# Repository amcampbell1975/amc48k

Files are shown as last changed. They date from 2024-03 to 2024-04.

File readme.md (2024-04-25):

# AMC48K
48 key Ortholinear keyboard.

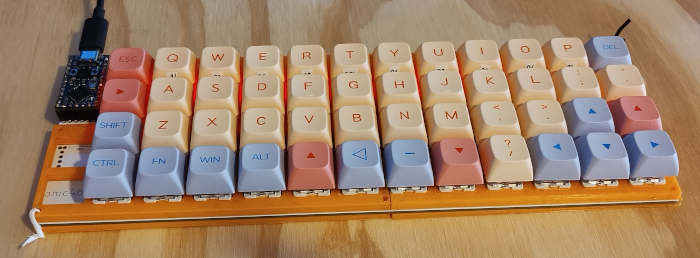
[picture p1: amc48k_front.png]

- RP2040 promicro.
- 48 RGB leds
- Rotary encoder
- 3D printed case, and plate.

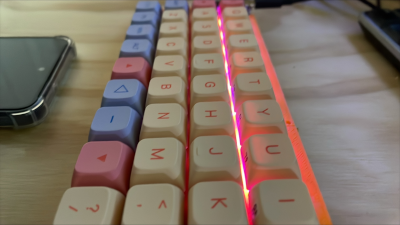
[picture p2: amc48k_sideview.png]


# How to Build
- [Components](components/bom.md) required.
- [PCB](pcb/readme.md) created using kicad
- [Case](case/readme.md) 3d printed. Created using openscad.

# QMK Features
- Caps word  (tap both shift to activate next word caps lock)
- Mouse emulation
  - FN "Arrow keys" 
- Dynamic Macros: Record and Replay Macros in Runtime
  - Lower "a" record 1
  - Lower "z" play 1
  - Lower "s" record 2
  - Lower "x" play 2
  - Lower "d" Stop recording 

# Other stuff...

## RP2040 startup
[Double tap bootmode](https://docs.qmk.fm/#/platformdev_rp2040?id=double-tap)  This is enabled be default.

## ANSI vs ISO backslash
I use a UK (ISO) keyboard layout in the OS, however the keycaps are US (ANSI) style
- KC_NONUS_BACKSLASH	KC_NUBS	Non-US \ and |	✔	✔	✔
- KC_BACKSLASH	KC_BSLS	\ and |	✔	✔	✔
- KC_NONUS_HASH	KC_NUHS	Non-US # and ~	✔	✔	✔

## to do 
- Rotary encoder

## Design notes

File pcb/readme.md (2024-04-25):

# PCB 
kicad

[kicad zip](amc48k_MANAFACTURED.zip)

# Schematic 
[amc48k.pdf](amc48k.pdf)

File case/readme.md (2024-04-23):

# Plate


## Split for small 3d printer bed.


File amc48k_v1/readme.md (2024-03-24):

# amc48k/amc48k_v1

amc48k/amc48k_v1

*A short description of the keyboard/project*

* Keyboard Maintainer: [amc](https://github.com/amc)
* Hardware Supported: *The PCBs, controllers supported*
* Hardware Availability: *Links to where you can find this hardware*

Make example for this keyboard (after setting up your build environment):

    make amc48k/amc48k_v1:default

Flashing example for this keyboard:

    make amc48k/amc48k_v1:default:flash

See the [build environment setup](https://docs.qmk.fm/#/getting_started_build_tools) and the [make instructions](https://docs.qmk.fm/#/getting_started_make_guide) for more information. Brand new to QMK? Start with our [Complete Newbs Guide](https://docs.qmk.fm/#/newbs).

## Bootloader

Enter the bootloader in 3 ways:

* **Bootmagic reset**: Hold down the key at (0,0) in the matrix (usually the top left key or Escape) and plug in the keyboard
* **Physical reset button**: Briefly press the button on the back of the PCB - some may have pads you must short instead
* **Keycode in layout**: Press the key mapped to `QK_BOOT` if it is available

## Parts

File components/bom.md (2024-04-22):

# Bill of Materials 
What is requried.

## keycaps
PBT Keycap XDA Highly Sublimated Technology Personalized Key Caps For Cherry MX Switch Game Mechanical Keyboard. Cotton candy theme

https://www.aliexpress.com/item/1005005732144367.html

￡6.84 + Tax + Shipping



## Switches (48 required)
10Pcs 3 Pin KeyCaps Brofwn Mechanical Keyboard Switch for Cherry MX Keyboard

https://www.aliexpress.com/item/33007890748.html

£1.33 * 5 = £6.65 + Tax + Shipping



## Hot Swap Switches (48 required)
Kailh Hot-swappable PCB socket Hot Plug (qty 50)

https://www.aliexpress.com/item/1005006105695230.html

£5.51 + Tax + Shipping

![image](https://git
£0.91 + Taxhub.com/amcampbell1975/amc48k/assets/65419433/901e2cca-c47a-4f12-8009-df3bff7874ff)

## Diodes (48 Required)
1N4148 SOD-123 

https://www.aliexpress.com/item/1005006207944104.html

£0.91 + Tax + Shipping



## Micro Controller Socket.
10 x Pair Plug Jack (Male & Female required)

https://www.aliexpress.com/item/1005002545449541.html

£1.45 + Tax + Shipping



## RGB LEDS (48 required)
SK6812 MINI-E  (Make sure it is the "MINI-E" as the MINI has a different package)

https://www.aliexpress.com/item/1005005473596808.html

£4.01 + Tax + Shipping



## Cap for LEDs (48 requried)
10uf caps 0805 SMD Chip Multilayer Ceramic Capacitor
https://www.aliexpress.com/item/1005005690917856.html

£0.69 + Tax + Shipping



## Micro Controller RP2040 with promicro footprint.
RP2040 with promicro footprint. 
RP2040 Pro Micro Raspberry PI PICO Development Board Dual-Core

https://www.aliexpress.com/item/1005006377576656.html

£3.68  + Tax + Shipping



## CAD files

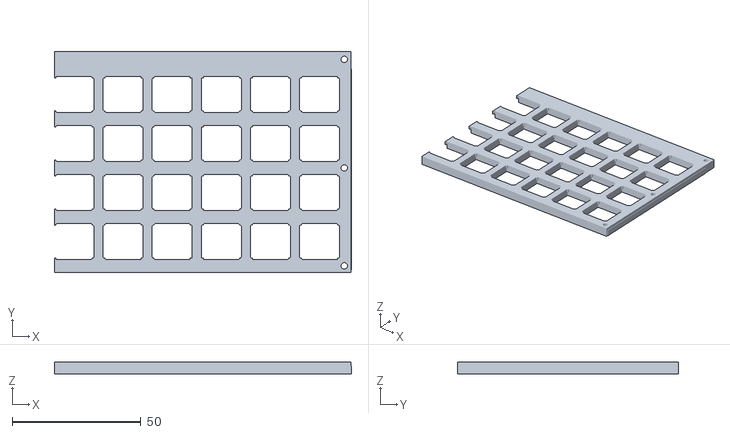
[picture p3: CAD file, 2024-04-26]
case/plate_right_v4.stl
115.2 x 85.8 x 4.50

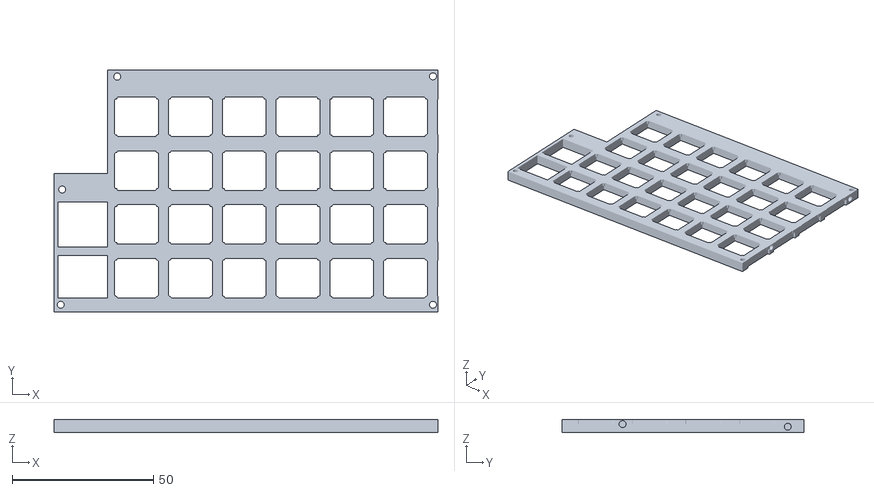
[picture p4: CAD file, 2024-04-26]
case/plate_left_v4.stl
136.0 x 85.8 x 4.50

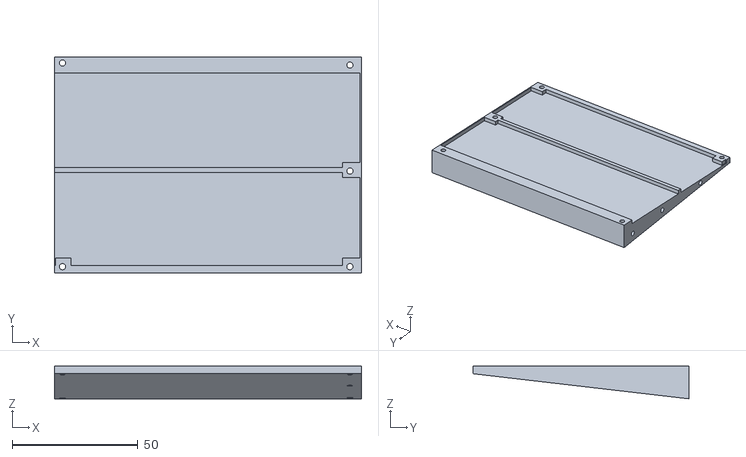
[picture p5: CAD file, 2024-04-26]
case/case_bottom_right_v2.stl
122.0 x 86.0 x 13.0

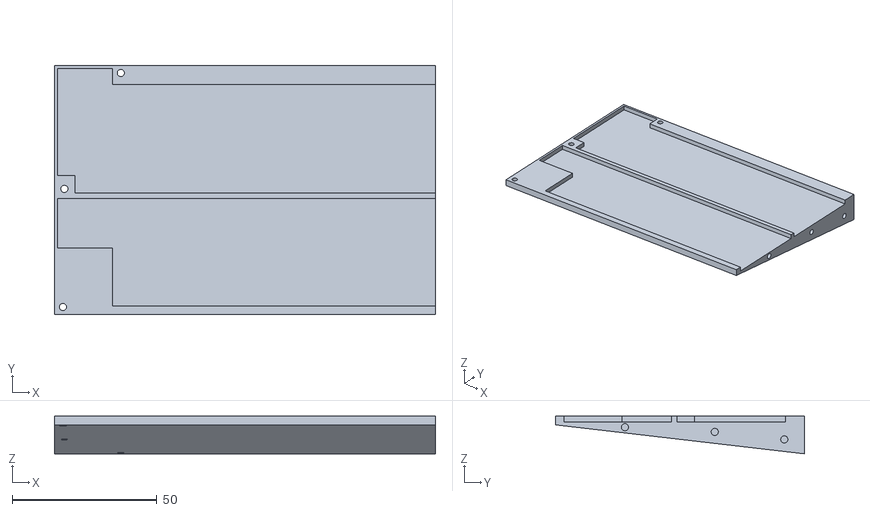
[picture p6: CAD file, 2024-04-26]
case/case_bottom_left_v2.stl
131.5 x 86.0 x 13.0

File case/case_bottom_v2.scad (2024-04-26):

$fn=20;

$CASE_THICKNESS = 3; // minus 3d printer tolerence



if (false)
    translate([0,0,-4])
    color("gray",1)
    rotate([180,180,180])
    translate([-45.9,129 ,-4.7])
    import ("amc48k_PCBv2.stl");


translate([0,0,-8.2]) 
difference()
{
 intersection()
 {  
     
     //$CHOP_POINT=119+(19.02*0)+0.4;  // Half and half chop point
     $CHOP_POINT=24+(19.02*6)+0.4-5;  // Half and half chop point
     //$CHOP_POINT=24+(19.02*1)+0.4;  // Half and half chop point
     
     // Small print section
//     rotate([0,0,3]) // rotate to create a diagonal split of the 2 halfs.
     {  
         if (false){
            translate([-100,-100,-10])
    //        cube([119,192,20]); //1x4
    //        cube([140,142,20]); //3x3
              cube([900,900,20]);  // Everything
         }
        else{
            //////////////////////////////
            // Half and half
            //////////////////////////////
            
            if(false){//6x4_left
                translate([-24,-30,-30])
                cube([$CHOP_POINT,192,40]); 
            }else{ //6x4_right
                translate([-24,-30,-30])
                translate([$CHOP_POINT,0,0])
                cube([$CHOP_POINT,192,40]); 
            }
         
        }
    }
    union(){
        
        //Main body
        translate([-22,-5,0])
        color("orange")    
        //cube([232,86-0.3,$PLATE_THICKNESS]);
        cube([235+18.5,86,$CASE_THICKNESS]);
    
   
        //Sloping base
        color("green")
        translate([-22,-5,0]) 
        rotate([0,90,0])
        linear_extrude(height = 235+18.5, center = false, convexity = 10, twist = 0, slices = 20, $fn = 16)
        polygon(points=[[0,0],[10,86],[0,86]]);
    }
         
    //         else
    //             translate([-5+2.5-18.5,-5,0])
    //             color("re2")    
    //             cube([235+18.5,86,$PLATE_THICKNESS]);
    //         
    //         
    //         
    //         linear_extrude(height=5, center=true, convexity= 10){
    //             import("kbplate.svg");
    //         }
    //     }
    // }    
 }
 // Remove bolt holes
 // Bolt Hole bottom left
 translate([-19.1,-2.4,-10])
 cylinder(h=20,d=2.5);

 // Bolt Hole Middle left
 translate([-19.1,-2.4,-10])
 translate([0.5,40.8,0])
 cylinder(h=20,d=2.5);

 // Bolt Hole Top left
 translate([-19.1,-2.4,-10])
 translate([20,80.8,0])
 cylinder(h=20,d=2.5);

 // Bolt Hole Top middle
 translate([-19.1,-2.4,-10])
 translate([131.8,80.9,0])
 cylinder(h=20,d=2.5);
 
 // Bolt Hole Bottom middle
 translate([-19.1,-2.4,-10])
 translate([131.8,0.0,0])
 cylinder(h=20,d=2.5);

 // Bolt Hole Bottom right
 translate([-19.1,-2.4,-10])
 translate([246.0,0.0,0])
 cylinder(h=20,d=2.5);
 
 // Bolt Hole middle right
 translate([-19.1,-2.4,-10])
 translate([246.0,38.0,0])
 cylinder(h=20,d=2.5);

 // Bolt Hole Top right
 translate([-19.1,-2.4,-10])
 translate([246.0,80.1,0])
 #cylinder(h=20,d=2.5);
 
 // Horizonal join top
 translate([107.0-40,76.0-2,-5])
 rotate([0,90,0])
 #cylinder(h=80,d=2.5);

 // Horizonal join middle
 translate([107.0-40,50.0,-2.4])
 rotate([0,90,0])
 #cylinder(h=80,d=2.5);
 
  // Horizonal join bottom
 translate([109.9-40,19,-0.8])
 rotate([0,90,0])
 #cylinder(h=80,d=2.5);
 
 difference(){
    translate([-21.0,-4,1])
    cube([252.5-0.5,84,$CASE_THICKNESS-0.5]);
    
    // Bottom left 
    translate([-21.0,-4,1])
    cube([19,22,$CASE_THICKNESS-0.5]);
    
    // Left middle 
    translate([-21.0,35,1])
    cube([6,8,$CASE_THICKNESS-0.5]);

    // Left middle 
    translate([224.0,33,1])
    cube([7,6,$CASE_THICKNESS-0.5]);
        
    // Top edge
    translate([-2,74.5,1])
    cube([233,5.5,$CASE_THICKNESS-0.5]);
      
    // Bottom edge
    translate([-2,-5,1])
    cube([233,3,$CASE_THICKNESS-0.5]);

    // Middle support
    translate([-21,35,1])
    cube([245,2,$CASE_THICKNESS-0.5]);
    
    // middle bottom
    translate([110.0,-5,1])
    cube([6,6,$CASE_THICKNESS-0.5]);
        
    // middle right
    translate([224.0,-5,1])
    cube([7,6,$CASE_THICKNESS-0.5]);
  
 }

}



 
 
//#linear_extrude(height=5, center=true, convexity= 10){
//         import("kbplate_bot.svg");
//}
 
 
 if(false)
 translate([8,7,12])
{

	//1. steam
	color("brown"){
		//1.1. l-r tab is 1.35mm
		translate([0,0,-3.62/2])
			cube([1.35,4.5,3.62], center=true);
		//1.2. f-b tab is 1.15mm. it has a smal notch that i will ignore.
		translate([0,0,-3.62/2])
			cube([4.5,1.15,3.62], center=true);
		//1.3. base. it has a chamfered top that i will ignore.
		translate([0,0,-5.62])
			cube([7.2,5.56,4], center=true);
	}
	// 2. top
	color("grey"){
		difference(){
			// make a trapezoid with the general shape (volume?) of the top
			hull(){
				translate([0,0,-4]) //distance from top of switch... some i measured 3.9 others 4.2... so leaving at 4
					cube([9.87,10.62,0.1], center=true);
				translate([0,0,-4 -5.2]) // bottom has a measured 5.3... so move 5.2 and use the 0.1 bellow
					cube([14.58,14.58,0.1], center=true);
			}

		// and subtract:
		// the front led. NOTE: totally off... measured by eye. just for astetics
		// adding just so there is a visual cue of the direction
			translate([0,-4.7,-6])
				cylinder(r=3/2, h=6, center=true);
			translate([0,-5.5,-6])
				cube([8,4,5], center=true);
		// the four corners
			// TODO waste of time? this is all for looks, you shouldn't invade any of that space anyway...
		}
	}

	// 3. bottom
	color("green")
		// 3.1 main body volume
		hull(){
				translate([0,0,-4 -5.3]) //steam + top
					cube([13.98,13.98,0.1], center=true);
				translate([0,0,-4 -5.3 -2.2]) //steam + top + straigth part
					cube([13.98,13.98,0.1], center=true);
				translate([0,0,-4 -5.3 -5.5]) //steam + top + bottom (measured 5.5)
					cube([12.74,13.6,0.1], center=true);
		}
		// 3.2 tabs
		// note: only measured the lenght, if they are slightly off-center, this will be all wrong :)
		color("black")
		difference(){
			translate([0,0,-4 -5.3 -0.82/2]) //steam + top
				cube([15.64,15.64,0.82], center=true);
			translate([0,0,-4 -5.3 -0.82/2  ]) // front-back cut
				cube([5.64,20,0.82 +2], center=true);
			translate([0,0,-4 -5.3 -0.82/2  ]) //side cut
				cube([20,11.64,0.82 +2], center=true);
		}

		// 3.3 tab (plate snap on). to use this mechanically, you have to take into account the bending (as it will move the bottom part slightly up...) just for gross reference here for now
		color("white"){
			// 3.3.1 top
			translate([0,0,-4 -5.3 -0.82/2  ]) // front-back cut
				cube([1.82,16.33,0.82], center=true);
			// 3.3.2 bottom
			difference(){
				hull(){
					translate([0,0,-4 -5.3 -0.82/2 -1.76  ]) // front-back cut
						cube([3.65,14,0.1], center=true);
					translate([0,0,-4 -5.3 -0.82/2 -2.2  ]) // front-back cut
						cube([3.65,14.74,0.1], center=true);
					translate([0,0,-4 -5.3 -0.82/2 -2.89  ]) // front-back cut
						cube([3.65,14,0.1], center=true);
				}
				translate([0,0,-4 -5.3 -0.82/2 -1.76   ]) // front-back cut
					cube([2.2,20,4], center=true);

			}
		}

		// 4. bottom guides
		// again, i'm assuming everything is centered...
		color("darkGreen"){
			// 4.1 cylinder
			translate([0,0,-4 -5.3 -5.5 -2/2]) //steam + top + bottom (measured 5.5)
				cylinder(r=3.85/2, h=2, center=true);
			translate([0,0,-4 -5.3 -5.5 -2 -1/2]) //steam + top + bottom (measured 5.5)
				cylinder(r2=3.85/2, r=2.8/2, h=1, center=true);
			// 4.2 PCB pins
			translate([4.95,0,-4 -5.3 -5.5 -2/2]) //steam + top + bottom (measured 5.5)
				cylinder(r=1.6/2, h=2, center=true);
			translate([4.95,0,-4 -5.3 -5.5 -2 -1/2]) //steam + top + bottom (measured 5.5)
				cylinder(r2=1.6/2, r=1/2, h=1, center=true);
			translate([-4.95,0,-4 -5.3 -5.5 -2/2]) //steam + top + bottom (measured 5.5)
				cylinder(r=1.6/2, h=2, center=true);
			translate([-4.95,0,-4 -5.3 -5.5 -2 -1/2]) //steam + top + bottom (measured 5.5)
				cylinder(r2=1.6/2, r=1/2, h=1, center=true);
		}

		// 5. pins
		color("orange"){
			translate([-3.77,2.7,-4 -5.3 -5.5 -3.1/2]) //steam + top + bottom (measured 5.5)
				cube([.86, 0.2,3.1], center=true);
			translate([2.7,5.2,-4 -5.3 -5.5 -3.1/2]) //steam + top + bottom (measured 5.5)
				cube([.86, 0.2,3.1], center=true);
		}

}

 
 /*
 }
 */
 

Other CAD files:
case/plate_v4.scad

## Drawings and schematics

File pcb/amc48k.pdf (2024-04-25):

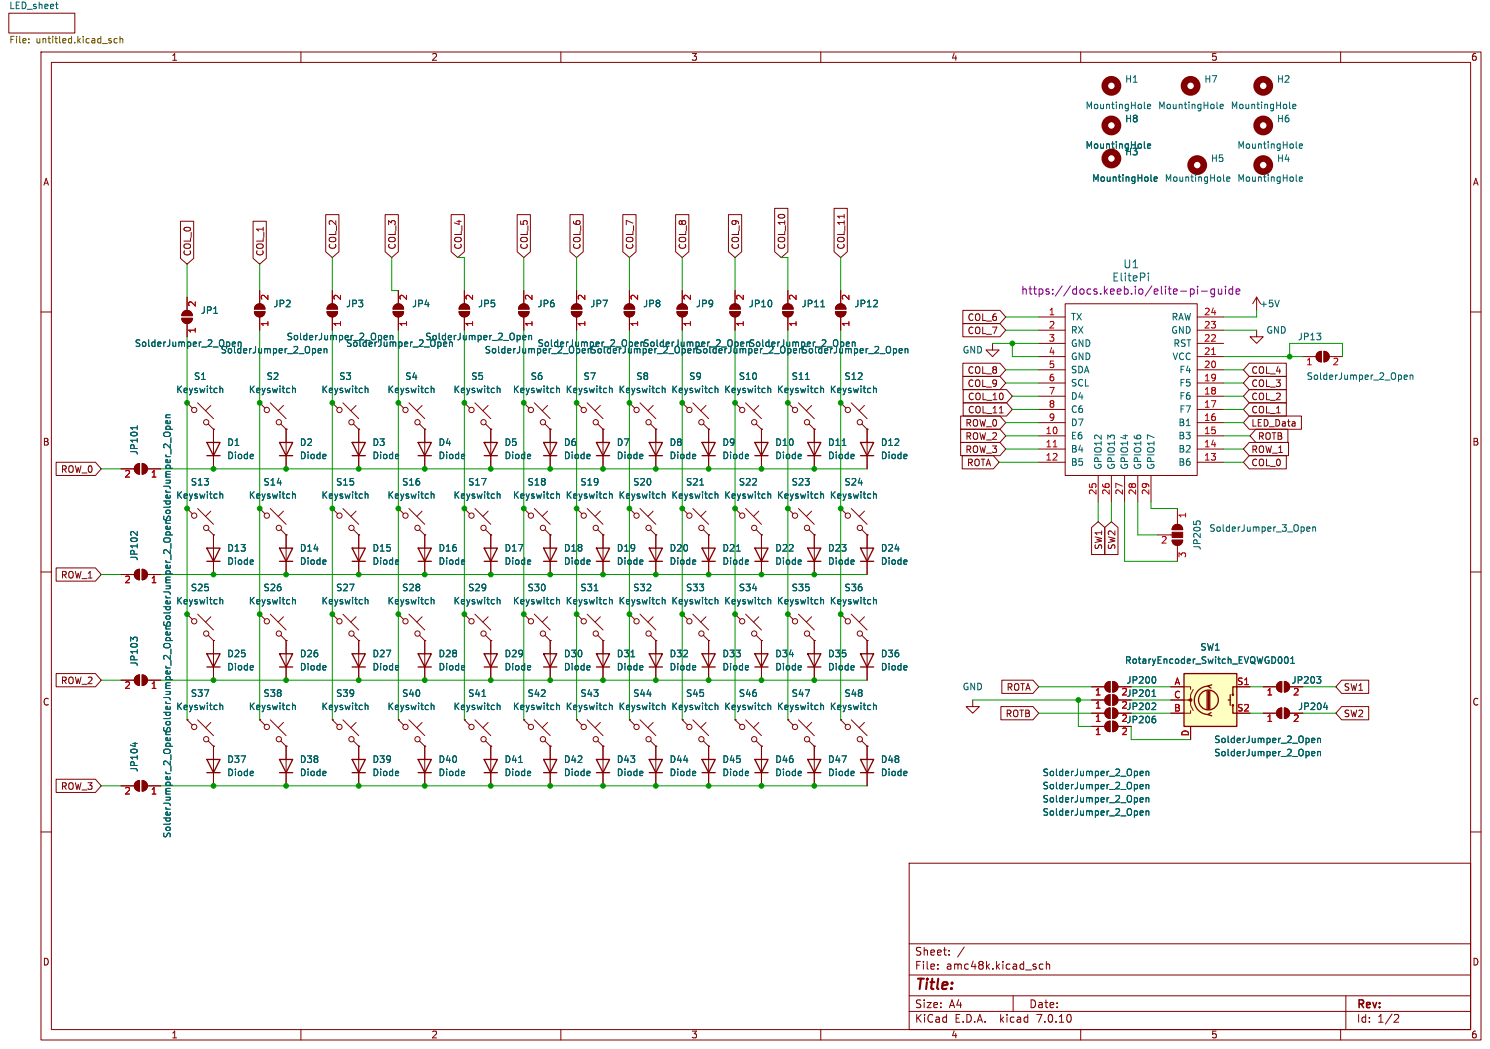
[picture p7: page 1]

1 2 H8 MountingHole H3 MountingHole D46 Diode D45 Diode S47 Keyswitch S46 Keyswitch D34 Diode D33 Diode D48 Diode S48 Keyswitch D47 Diode D35 Diode D36 Diode S45 Keyswitch D23 Diode D24 Diode S35 Keyswitch D22 Diode S36 Keyswitch S34 Keyswitch S33 Keyswitch D21 Diode SW1 RotaryEncoder_Switch_EVQWGD001 A

1 2 JP6 SolderJumper_2_Open D44 Diode D3 Diode S14 Keyswitch S41 Keyswitch D17 Diode S17 Keyswitch S28 Keyswitch S16 Keyswitch D16 Diode S29 Keyswitch S40 Keyswitch D40 Diode D2 Diode S30 Keyswitch S18 Keyswitch S19 Keyswitch D41 DiodeS42 Keyswitch S20 Keyswitch D29 Diode D28 Diode D20 Diode S3 Keyswitch D1 Diode S2 Keyswitch S1 Keyswitch D18 Diode D30 Diode D19 Diode COL_2

1 2 D3 Diode S14 Keyswitch S3 Keyswitch S2 Keyswitch S1 Keyswitch D1 Diode D2 Diode S15 Keyswitch JP101 SolderJumper_2_Open 2 1 S13 Keyswitch
JP1 SolderJumper_2_Open

1 2 JP9 SolderJumper_2_Open D36 Diode S45 Keyswitch D23 Diode D24 Diode S35 Keyswitch D22 Diode S36 Keyswitch S34 Keyswitch S33 Keyswitch D21 Diode S4 Keyswitch D43 Diode D4 Diode D5 Diode S43 Keyswitch S44 Keyswitch

1 2 JP5 SolderJumper_2_Open D42 Diode S32 Keyswitch D31 Diode D32 Diode S31 Keyswitch
JP5 SolderJumper_2_Open

1 2 JP11 SolderJumper_2_Open S22 Keyswitch S23 Keyswitch S21 Keyswitch D35 Diode
JP9 SolderJumper_2_Open

1 2 D15 Diode S27 Keyswitch D27 Diode D39 Diode D38 Diode D14 Diode D26 Diode S39 Keyswitch S26 Keyswitch D25 Diode D13 Diode S25 Keyswitch S38 Keyswitch D37 Diode S37 Keyswitch JP103 SolderJumper_2_Open 2 1 JP104 SolderJumper_2_Open 2 1 JP102 SolderJumper_2_Open 2 1 D6 DiodeS7 Keyswitch S6 Keyswitch

1 2 JP1 SolderJumper_2_Open D15 Diode S27 Keyswitch D27 Diode D39 Diode

Id: 1/2 Title: File: amc48k.kicad_sch Sheet: /

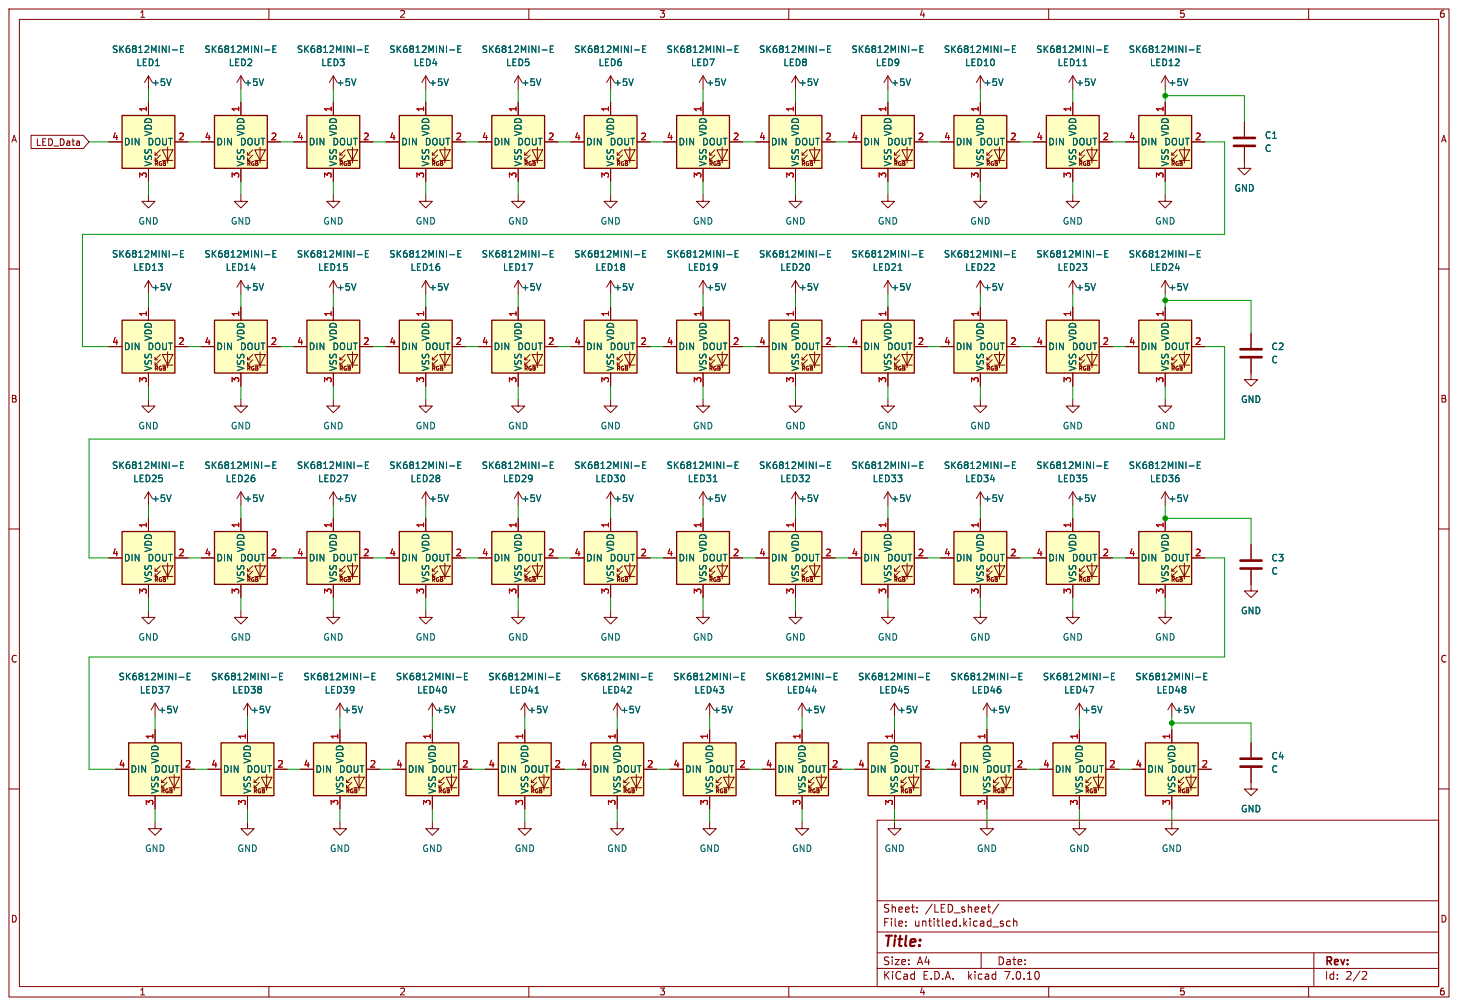
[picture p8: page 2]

Id: 2/2 Title: File: untitled.kicad_sch Sheet: /LED_sheet/

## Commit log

2024-03-26 Update info.json to add RGB LEDs
2024-03-26 Update keymap.c add rgb leds swap tab-esc
